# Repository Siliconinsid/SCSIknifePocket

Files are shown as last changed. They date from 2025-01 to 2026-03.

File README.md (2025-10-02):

# SCSIknife Pocket

SCSIknife Pocket - The SCSI jump drive.

SCSIknife Pocket is a ZuluSCSI™ PICO OSHW derivative, compatible with the ZuluSCSI™ PICO firmware.

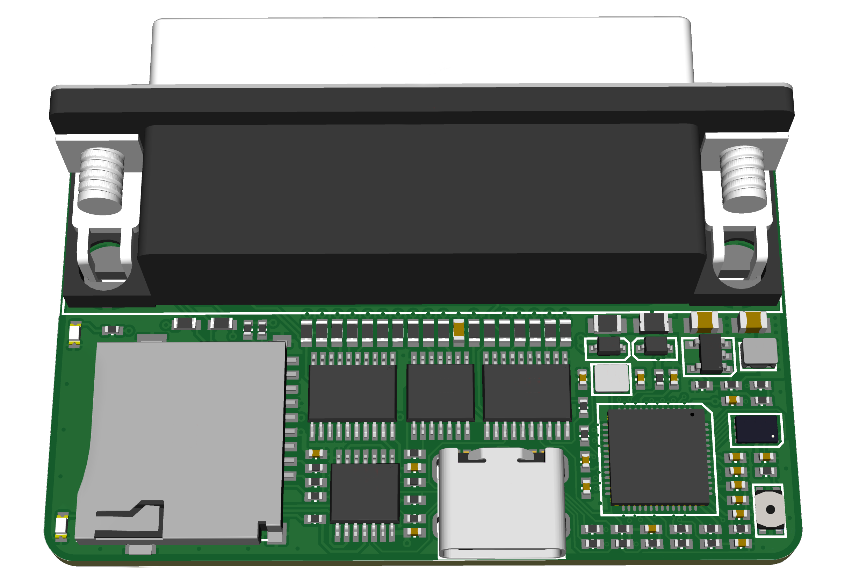
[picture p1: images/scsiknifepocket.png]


SCSIknife Pocket is an extremely compact SCSI disk drive emulator designed to be plugged externally to a computer or SCSI enabled device.

# Hardware

SCSIknife Pocket require 5.0VDC ± 0.5V which can be supplied by the SCSI termination or USB-C. SCSIknife Pocket is available in DB25, HD50 or Centronics50 version.

SCSI DB25 connector is male, but can be replaced with DB25 female if soldered on the underside of the board. The same apply for other connector types.

# Firmware

SCSIknife Pocket is 100% compatible with the ZuluSCSI™ PICO firmware.
As such, flashing instructions can be found [there](https://github.com/ZuluSCSI/ZuluSCSI-firmware)

To update the firmware, download the universal `.zip` archive and place it on a SD card, firmware will be updated at power up.
Alternatively, place the PICO version of the `.bin` file on the SD card. Do not use the RP2040 or any RP2350 based versions.
If for some reason SCSIknife is unresponsive or if the wrong firmware is flashed, restore by pressing and holding the “Bootloader” button before plugging in the USB C connection to a computer. SCSIknife will appear as a drive on the desktop. Drop the PICO firmware file in `.uf2` format on the disk and SCSIknife will automatically update and disconnect itself upon completion. 

# Gerber generation

This PCB was designed with Adobe Illustrator, and exported as SVG files.

These SVG files are then converted to Gerber using the following tools:
* [Gerbolyze](https://github.com/jaseg/gerbolyze)
* [svg-to-gerber](https://github.com/Altomare/svg-to-gerber): gerbolyze wrapper + drill file generation

If you need to re-generate gerbers:
```shell
# Illustrator uses 72 DPI instead of the usual 96 for SVG files
svg-to-gerber.py SCSIknife/svg SCSIknife/gerber 72

# If you end up with a negative gerber on some layers, 
# re-run the svg-flatten command seen in logs without -f.
# It seems to behave differently on different setups
```

# License and disclaimer

SCSIknife Pocket is based on ZuluSCSI™ PICO OSHW, which can be found here:
* [ZuluSCSI™ Pico OSHW](https://github.com/ZuluSCSI/ZuluSCSI-Pico-OSHW)
* [ZuluSCSI™ Firmware](http://github.com/ZuluSCSI/ZuluSCSI-firmware)

ZuluSCSI™ is a registered trademark of Rabbit Hole Computing.
Rabbit Hole Computing is not responsible for the SCSIknife hardware and does not provide technical support and troubleshooting regarding SCSIknife related issues.

SCSIknife Pocket inherits the CERN-OHL-S-2.0 license from ZuluSCSI Pico

See [license.txt](LICENSE.txt)

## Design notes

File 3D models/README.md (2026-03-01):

# Creation of a circuit enclosure

The goal of this project is to create an enclosure for the [SCSI Knife Pocket](https://github.com/Siliconinsid/SCSIknifePocket) circuit.

## A prerequisite to the goal
Such a goal is generally fulfilled thanks to a 3D model of the finished circuit, a side-product of the CAD worflow used to design the circuit, used as a guide to design the enclosure around it.

In this case, the author has provided a PDF image of the layout of the main PCB. A bit of elaboration is needed before to tackle the main goal, the enclosure itself.

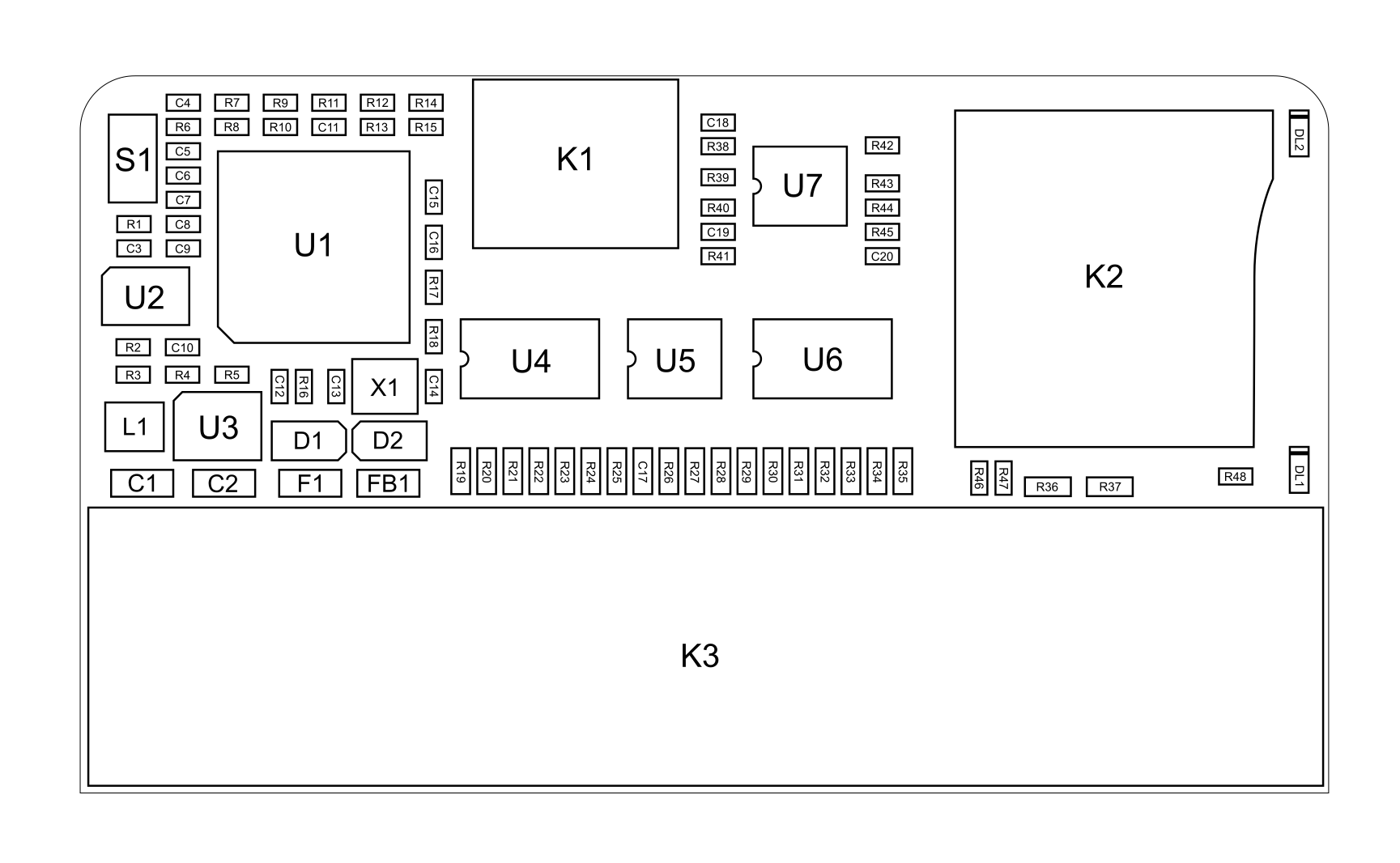
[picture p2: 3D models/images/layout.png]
 

**Note:** In addition to the main goal, attention will be paid to the procedures, they must be simple and reproducible with further versions of the circuit. 

Open Source tools used in this part of the project: 

* **Inkscape** is used to work on the SVG file 
* **FreeCAD** is used for the mechanical design.

An account on the [GrabCAD portal](https://grabcad.com) is also used.

The overall procedure is to start from the layout of the PCB, to simply it, then to import its geometry into the CAD system used for the enclosure design. The geometry of the circuit is transfered from the SVG to the CAD system, then ready-made 3D models of the components are added to recreate a realistic volumetry of the fully equiped circuit.

## Prerequisite elaboration
### Simplify the layout
The input is the file *schematcs/layout.pdf*, it is imported into Inkscape, an Adobe Illustrator® like tool.
Most components of the circuit are low profile CMS components, they require next to nothing in overhead space allocation. Therefore, only the footprint of the largest ones, two connectors and a memory card reader are retained and their precise placement transferred to FreeCAD. Only those four paths remain, the PCB outline and the footprint of the main components.

The result is exported as pcb_simplified.svg

 

### Import into the CAD system
FreeCAD is divided in multiple *Workbenches*, each one is specialized in some specific tasks.

* *Sketcher*: Used to streamline the paths and to reduce all of the remaining "Degrees Of Freedom" or DOF. 
* *Draft*: Used to transform the drawing into CAD sketches.
* *Part*: Used to compose a simplified 3D model of the circuit.

The import happens in the *Draft* workbench, choose *Import...* in the **File** menu, and select *simplified_pcb.svg*, then the second option *"As a geometry"*. Four objets are added to the tree of the model. Select each of them then click on the red/blue icon in the top toolbar to transform each path into a sketch.  Rename them for an easy selection.
Change to the *Sketcher* Workbench. The PCB and the Card Reader have arcs composed with multiple segments causing some green cluttering of the drawing.
    * Replace multiple segments with single arcs primitives. Deactivate all of the constraints, the total number of DOFs is then displayed. 
    * Reduce this number to nothing, with the paths highlighted in a single colour: To do so, add a "blocker" (red X in a circle) constraint on some of the edges. If the addition is not effective in decreasing the number of DOFs, just undo it and try another one. Additional attention is required for the PCB outline which needs to be a closed path. Examine the 6 vertices, if any does not seem a perfect circle, select them and apply a *Coincidence* constraint, reducing all neighbour points to a single one.

### Design and populate the Circuit 3D model

* Give some thickness (about 1.6 mm) to the PCB, by extruding the PCB outline upwards in the *Draft* workbench. This is the only **design** operation performed with this CAD tool.
* Populate the PCB with library 3D models of the 3 components. GrabCAD is a convenient resource for them.    
    * [The DB-25 female angle connector, labeled "AB2_DB25\_F\_RA"](https://grabcad.com/library/db25-female-right-angle-connector-1)
    * [The USB-C female connector, labeled "HRO_TYPE-C-31-M-12"](https://grabcad.com/library/type-c-31-m-12-1)
    * [The TF card reader, labeled "L-KLS1-TF-0.03\_ALL001"](https://grabcad.com/library/tf-01a-1) 

To insert one of those library components, you can download it from the GrabCAD portal through Community/Library menu, after creation of a free account. Ideally, the files are in .STEP format, otherwise on-line tools exist to convert them. The STEP file will be opened as separate document in FreeCAD then the file with the abovementioned labels can be dragged and dropped into the PCB project tree view.

Each objet in FreeCAD can be "placed", then on top of the applied changes from the library view, they can be moved around or rotated again to match the alignment of their footprint in the CAD tool **TOP** view.

Select the component in the tree, in the bottom panel activate the "Data" tab to see and edit the values.

* Placement
    * Angle: ± multiples of 90° to orient the component
    * Axis: Only 1 and 0 values to indicate X, Y or Z 
    * Position: x,y,z distances in millimeters to move the component into its position, use top and front view for precise alignement, it is also recommended to toggle the visibility of the PCB (Eye icon in front of it or selection+spacebar). A vertical z nudge of 1.6 mm (thickness of PCB) is needed to place the component on the top surface of the PCB.
  
Should an additional transform be needed, change to "Part" workbench, select component in the tree and right-click for contextual menu, and select first option, arrows and circular handles allow for additional placement movements.

Finally, select the root of the tree, then select from menu File > Export, choose STEP as the output format, and the circuit 3D model is now saved as pcb_simplified.step

Achievement unlocked! Prerequisite ready! 

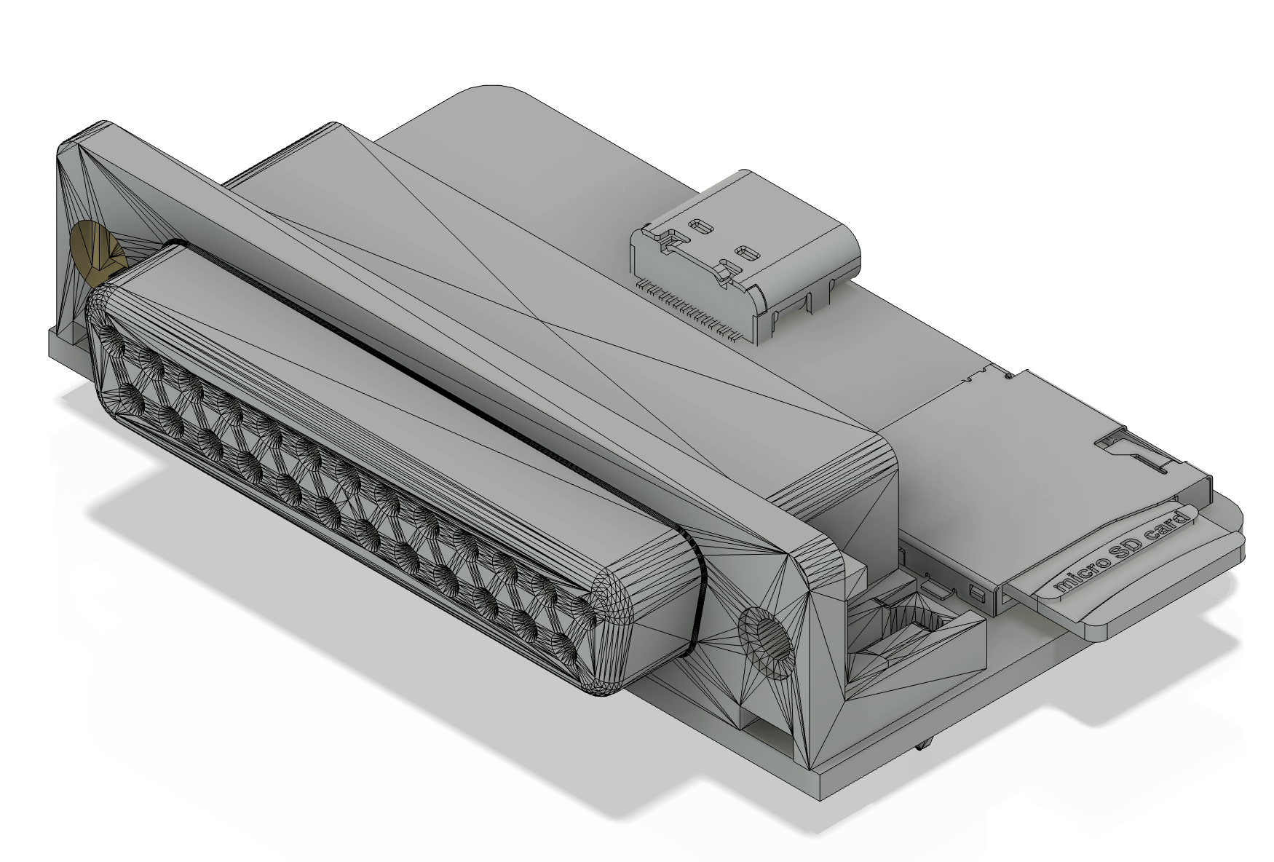
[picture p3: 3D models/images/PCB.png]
 

### Design of the enclosure

The main challenge of the design is to tightly maintain the PCB, with no sliding back and forth, and have the DB-25 "ears" register flush to the back of the computer on which it is mounted. In this version, a thin façade is used.

FreeCAD was first envisaged to finalize the design of this enclosure, however current bugs or lack of documentation on some recent changes have made it impossible to use. The free version of Autodesk Fusion 360 was used instead of that Open Source tool. After many attemps, the design with a sleeve and a back cover was retained. An optional plaque can display a logo, or some custom metal plaque could be stuck on the top surface of the sleeve.  

**Note:** A SCSI disk DB-25 should be of male gender, however only the female model was available as a 3D model. This has no impact on the design itself.

- Front view without sleeve
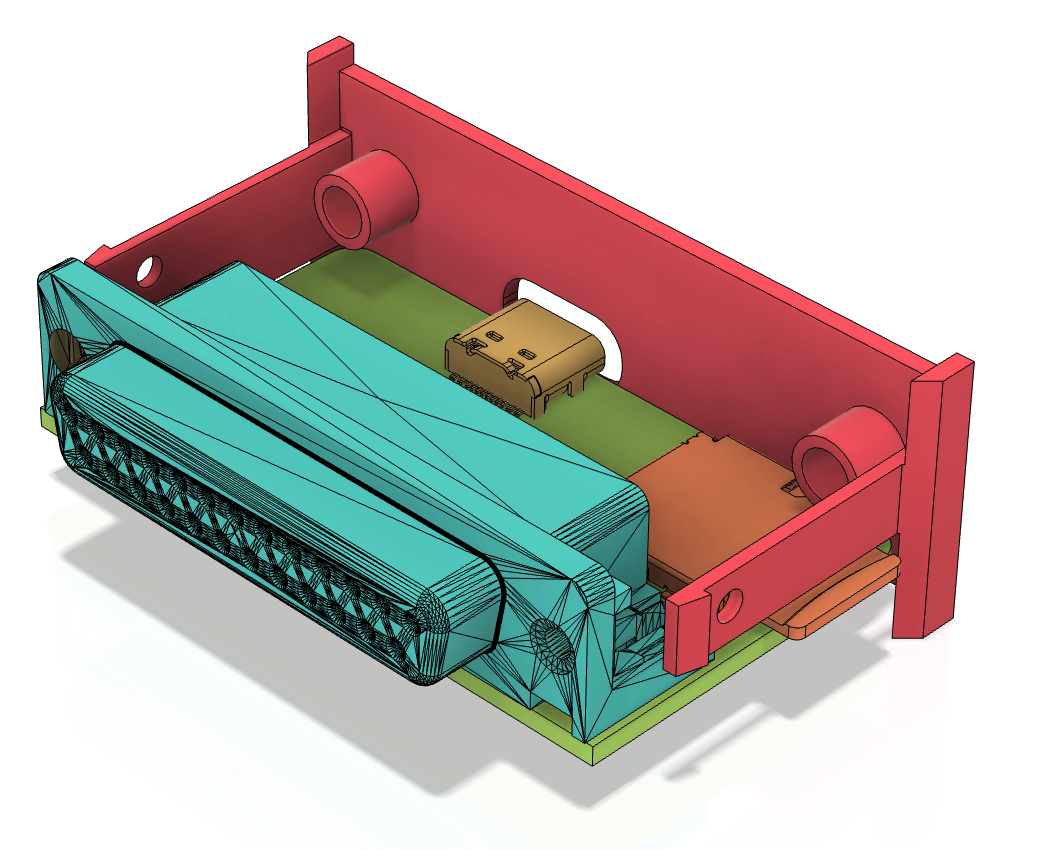
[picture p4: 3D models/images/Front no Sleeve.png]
 

- Front view with sleeve
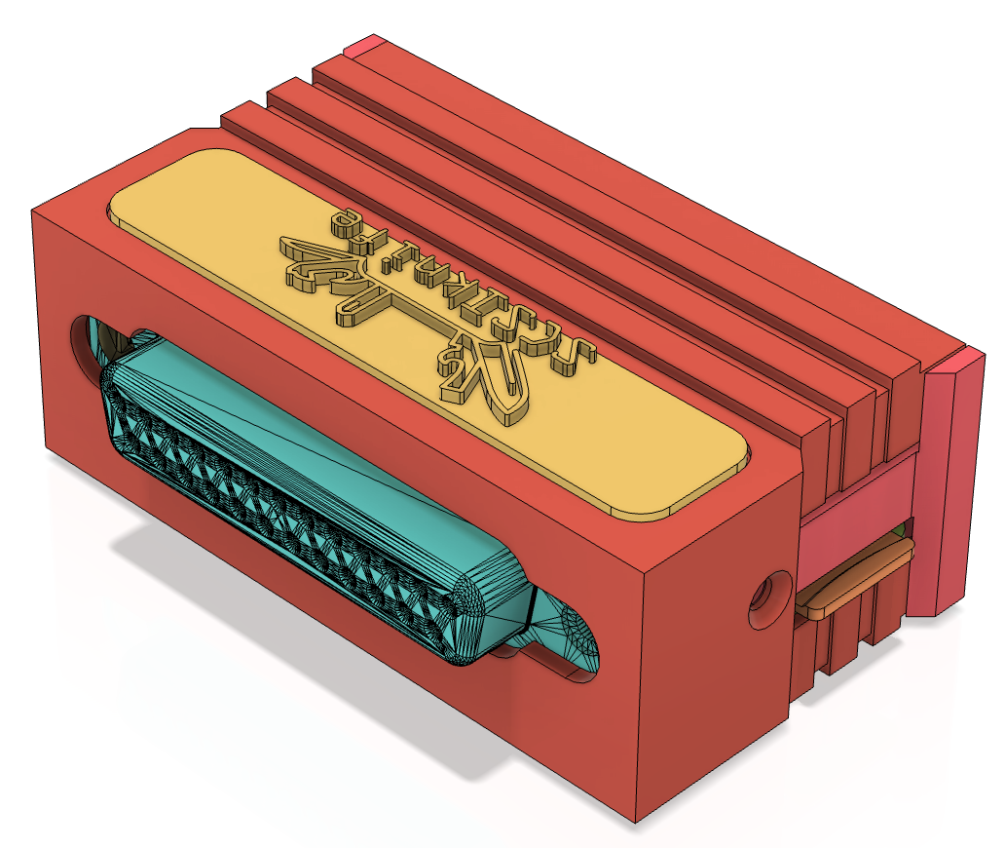
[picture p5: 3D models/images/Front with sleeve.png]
 

- Back view without back cap
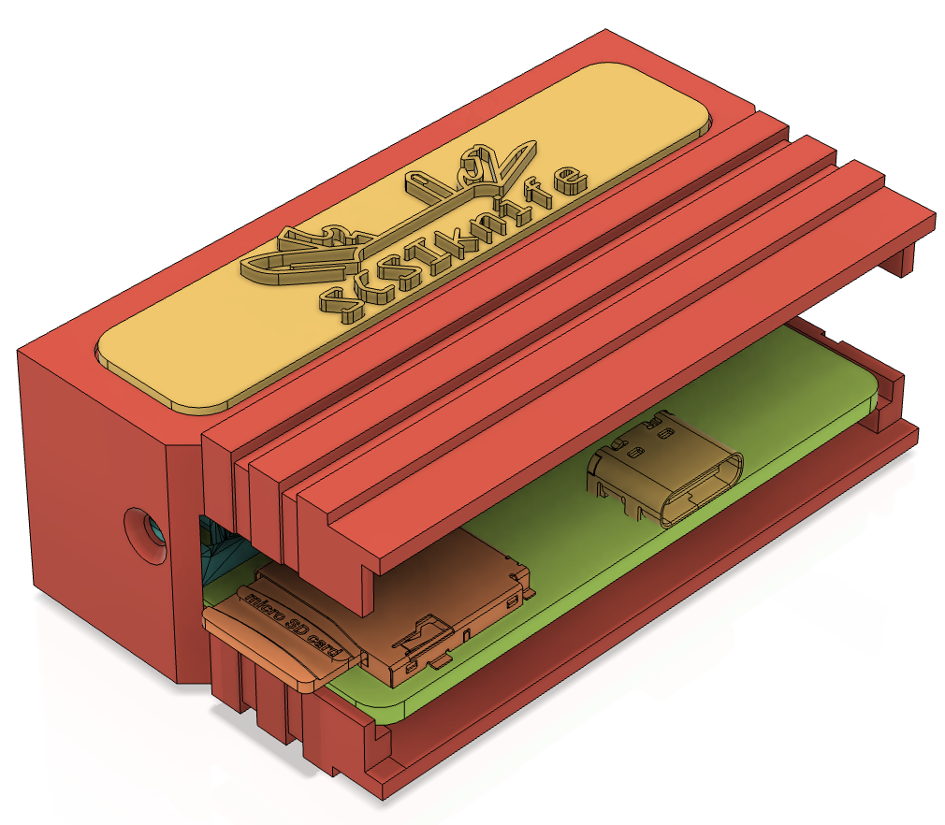
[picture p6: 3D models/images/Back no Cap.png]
 

- Back view with back cap
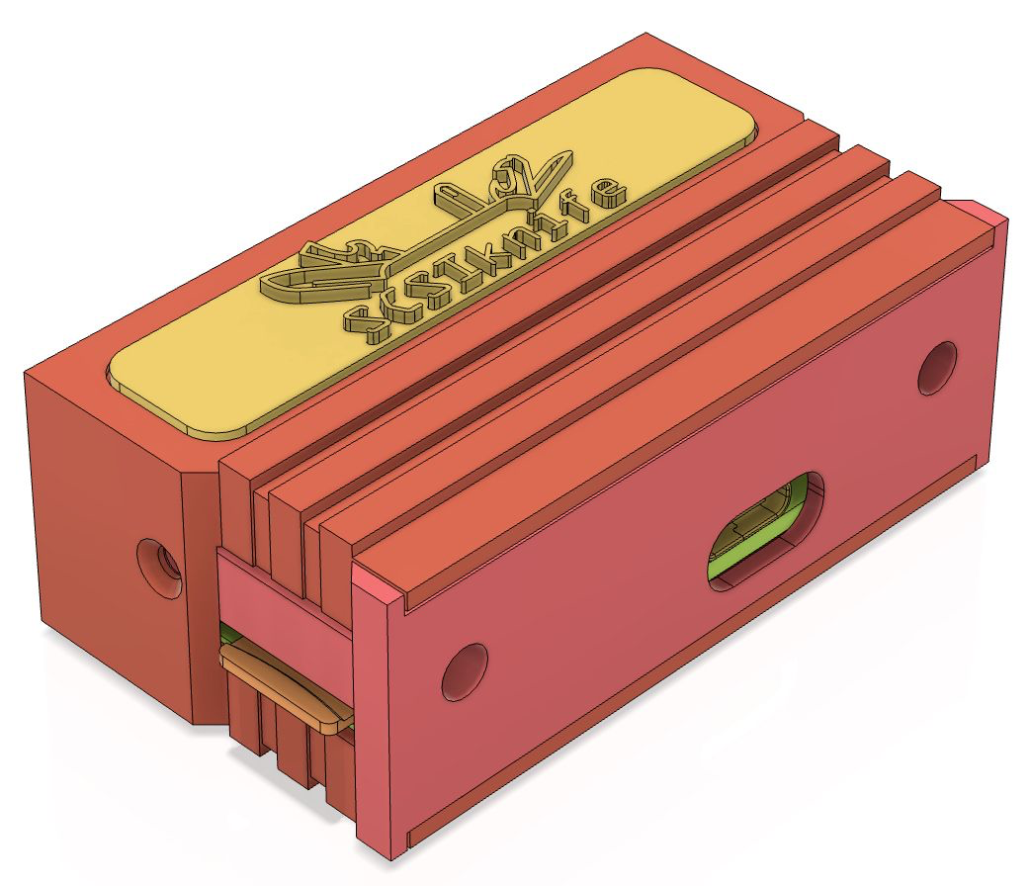
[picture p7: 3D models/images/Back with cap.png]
 

- Long screws could be added to secure the plug to the Mac. [Digikey](https://www.digikey.fr/fr/products/detail/norcomp-inc/160-000-050R031/1008061) has one reference for them.

- And finally...
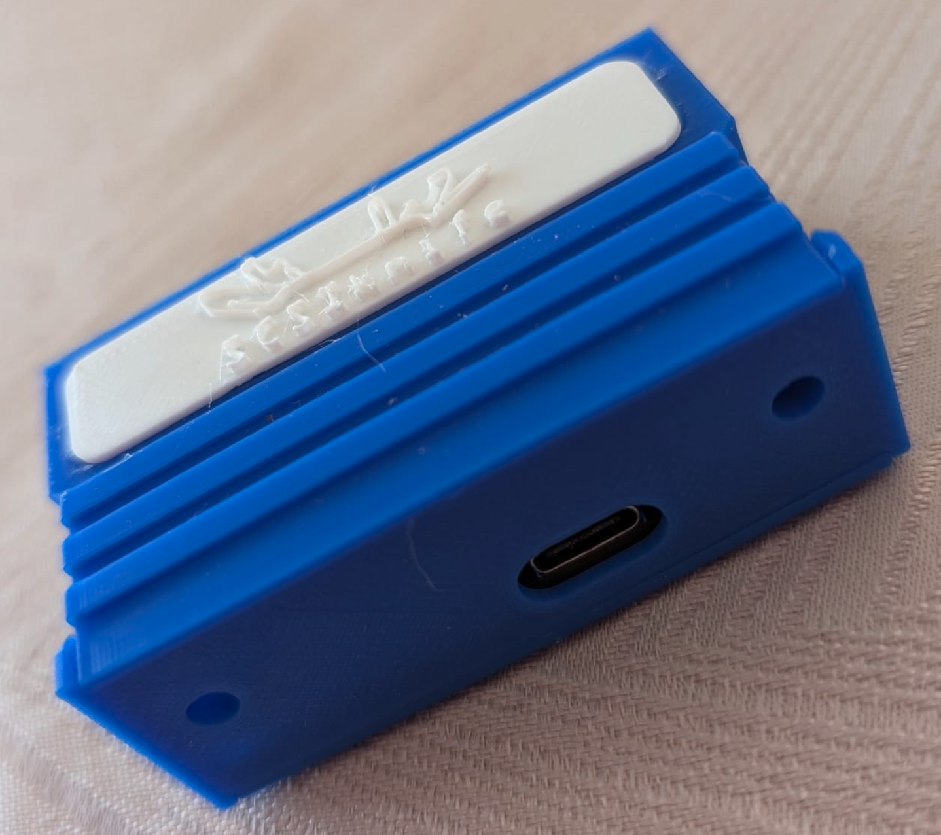
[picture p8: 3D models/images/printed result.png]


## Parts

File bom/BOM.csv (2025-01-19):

Designator | Component | Type | Value | Rating | Voltage | Tolerance | Package | Manufacturer | Part number
R1 | Resistor | Thick film | 1kΩ | 1/16W | 50V | 1% | 0402 | Vishay Dale | CRCW04021K00FKED
R2 | Resistor | Thick film | 5.6kΩ | 1/16W | 50V | 1% | 0402 | Vishay Dale | CRCW04025K60FKED
R3 | Resistor | Thick film | 10kΩ | 1/16W | 50V | 1% | 0402 | Vishay Dale | CRCW040210K0FKED
R4 | Resistor | Thick film | 90.9kΩ | 1/16W | 50V | 1% | 0402 | Vishay Dale | CRCW040290K9FKED
R5 | Resistor | Thick film | 20kΩ | 1/16W | 50V | 1% | 0402 | Vishay Dale | CRCW04022’0K0FKED
R6 | Resistor | Thick film | 200Ω | 1/16W | 50V | 1% | 0402 | Vishay Dale | CRCW0402200RFKED
R7 | Resistor | Thick film | 4.7kΩ | 1/16W | 50V | 1% | 0402 | Vishay Dale | CRCW04024K70FKED
R8 | Resistor | Thick film | 4.7kΩ | 1/16W | 50V | 1% | 0402 | Vishay Dale | CRCW04024K70FKED
R9 | Resistor | Thick film | 4.7kΩ | 1/16W | 50V | 1% | 0402 | Vishay Dale | CRCW04024K70FKED
R10 | Resistor | Thick film | 1kΩ | 1/16W | 50V | 1% | 0402 | Vishay Dale | CRCW04021K00FKED
R11 | Resistor | Thick film | 4.7kΩ | 1/16W | 50V | 1% | 0402 | Vishay Dale | CRCW04024K70FKED
R12 | Resistor | Thick film | 5.1kΩ | 1/16W | 50V | 1% | 0402 | Vishay Dale | CRCW04025K10FKED
R13 | Resistor | Thick film | 5.1kΩ | 1/16W | 50V | 1% | 0402 | Vishay Dale | CRCW04025K10FKED
R14 | Resistor | Thick film | 27Ω | 1/16W | 50V | 1% | 0402 | Vishay Dale | CRCW040227R0FKED
R15 | Resistor | Thick film | 27Ω | 1/16W | 50V | 1% | 0402 | Vishay Dale | CRCW040227R0FKED
R16 | Resistor | Thick film | 4.7kΩ | 1/16W | 50V | 1% | 0402 | Vishay Dale | CRCW04024K70FKED
R17 | Resistor | Thick film | 1kΩ | 1/16W | 50V | 1% | 0402 | Vishay Dale | CRCW04021K00FKED
R18 | Resistor | Thick film | 1kΩ | 1/16W | 50V | 1% | 0402 | Vishay Dale | CRCW04021K00FKED
R19 | Resistor | Thick film | 110Ω | 1/10W | 75V | 1% | 0603 | Vishay Dale | CRCW0603110RFKEA
R20 | Resistor | Thick film | 110Ω | 1/10W | 75V | 1% | 0603 | Vishay Dale | CRCW0603110RFKEA
R21 | Resistor | Thick film | 110Ω | 1/10W | 75V | 1% | 0603 | Vishay Dale | CRCW0603110RFKEA
R22 | Resistor | Thick film | 110Ω | 1/10W | 75V | 1% | 0603 | Vishay Dale | CRCW0603110RFKEA
R23 | Resistor | Thick film | 110Ω | 1/10W | 75V | 1% | 0603 | Vishay Dale | CRCW0603110RFKEA
R24 | Resistor | Thick film | 110Ω | 1/10W | 75V | 1% | 0603 | Vishay Dale | CRCW0603110RFKEA
R25 | Resistor | Thick film | 110Ω | 1/10W | 75V | 1% | 0603 | Vishay Dale | CRCW0603110RFKEA
R26 | Resistor | Thick film | 110Ω | 1/10W | 75V | 1% | 0603 | Vishay Dale | CRCW0603110RFKEA
R27 | Resistor | Thick film | 110Ω | 1/10W | 75V | 1% | 0603 | Vishay Dale | CRCW0603110RFKEA
R28 | Resistor | Thick film | 110Ω | 1/10W | 75V | 1% | 0603 | Vishay Dale | CRCW0603110RFKEA
R29 | Resistor | Thick film | 110Ω | 1/10W | 75V | 1% | 0603 | Vishay Dale | CRCW0603110RFKEA
R30 | Resistor | Thick film | 110Ω | 1/10W | 75V | 1% | 0603 | Vishay Dale | CRCW0603110RFKEA
R31 | Resistor | Thick film | 110Ω | 1/10W | 75V | 1% | 0603 | Vishay Dale | CRCW0603110RFKEA
R32 | Resistor | Thick film | 110Ω | 1/10W | 75V | 1% | 0603 | Vishay Dale | CRCW0603110RFKEA
R33 | Resistor | Thick film | 110Ω | 1/10W | 75V | 1% | 0603 | Vishay Dale | CRCW0603110RFKEA
R34 | Resistor | Thick film | 110Ω | 1/10W | 75V | 1% | 0603 | Vishay Dale | CRCW0603110RFKEA
R35 | Resistor | Thick film | 110Ω | 1/10W | 75V | 1% | 0603 | Vishay Dale | CRCW0603110RFKEA
R36 | Resistor | Thick film | 110Ω | 1/10W | 75V | 1% | 0603 | Vishay Dale | CRCW0603110RFKEA
R37 | Resistor | Thick film | 110Ω | 1/10W | 75V | 1% | 0603 | Vishay Dale | CRCW0603110RFKEA
R38 | Resistor | Thick film | 4.7kΩ | 1/16W | 50V | 1% | 0402 | Vishay Dale | CRCW04024K70FKED
R39 | Resistor | Thick film | 4.7kΩ | 1/16W | 50V | 1% | 0402 | Vishay Dale | CRCW04024K70FKED
R40 | Resistor | Thick film | 1kΩ | 1/16W | 50V | 1% | 0402 | Vishay Dale | CRCW04021K00FKED
R41 | Resistor | Thick film | 1kΩ | 1/16W | 50V | 1% | 0402 | Vishay Dale | CRCW04021K00FKED
R42 | Resistor | Thick film | 120Ω | 1/16W | 50V | 1% | 0402 | Vishay Dale | CRCW0402120RFKED
R43 | Resistor | Thick film | 4.7kΩ | 1/16W | 50V | 1% | 0402 | Vishay Dale | CRCW04024K70FKED
R44 | Resistor | Thick film | 4.7kΩ | 1/16W | 50V | 1% | 0402 | Vishay Dale | CRCW04024K70FKED
R45 | Resistor | Thick film | 4.7kΩ | 1/16W | 50V | 1% | 0402 | Vishay Dale | CRCW04024K70FKED
R46 | Resistor | Thick film | 4.7kΩ | 1/16W | 50V | 1% | 0402 | Vishay Dale | CRCW04024K70FKED
R47 | Resistor | Thick film | 4.7kΩ | 1/16W | 50V | 1% | 0402 | Vishay Dale | CRCW04024K70FKED
R48 | Resistor | Thick film | 51Ω | 1/16W | 50V | 1% | 0402 | Vishay Dale | CRCW040251R0FKED
C1 | Capacitor | MLCC | 10µF | X7R | 25V | 10% | 0805 | Murata | GRM21BZ71E106KE15L
C2 | Capacitor | MLCC | 22µF | X5R | 16V | 20% | 0805 | Samsung | CL10A226MO7JZNC
C3 | Capacitor | MLCC | 2.2uF | X5R | 25V | 20% | 0402 | Murata Electronics | GRM155R61E225ME11D
C4 | Capacitor | MLCC | 100nF | X7R | 50V | 20% | 0402 | Murata Electronics | GRM155R71H104ME14J
C5 | Capacitor | MLCC | 2.2uF | X5R | 25V | 20% | 0402 | Murata Electronics | GRM155R61E225ME11D
C6 | Capacitor | MLCC | 2.2uF | X5R | 25V | 20% | 0402 | Murata Electronics | GRM155R61E225ME11D
C7 | Capacitor | MLCC | 2.2uF | X5R | 25V | 20% | 0402 | Murata Electronics | GRM155R61E225ME11D
C8 | Capacitor | MLCC | 100nF | X7R | 50V | 20% | 0402 | Murata Electronics | GRM155R71H104ME14J
C9 | Capacitor | MLCC | 100nF | X7R | 50V | 20% | 0402 | Murata Electronics | GRM155R71H104ME14J
C10 | Capacitor | MLCC | 100nF | X7R | 50V | 20% | 0402 | Murata Electronics | GRM155R71H104ME14J
C11 | Capacitor | MLCC | 100nF | X7R | 50V | 20% | 0402 | Murata Electronics | GRM155R71H104ME14J
C12 | Capacitor | MLCC | 100nF | X7R | 50V | 20% | 0402 | Murata Electronics | GRM155R71H104ME14J
C13 | Capacitor | MLCC | 15pF | C0G | 50V | 1% | 0402 | Murata Electronics | GRM1555C1H150FA01D
C14 | Capacitor | MLCC | 15pF | C0G | 50V | 1% | 0402 | Murata Electronics | GRM1555C1H150FA01D
C15 | Capacitor | MLCC | 100nF | X7R | 50V | 20% | 0402 | Murata Electronics | GRM155R71H104ME14J
C16 | Capacitor | MLCC | 100nF | X7R | 50V | 20% | 0402 | Murata Electronics | GRM155R71H104ME14J
C17 | Capacitor | MLCC | 12pF | C0G | 25V | 2% | 0603 | Vishay Vitramon | VJ0603A120GXXCW1BC
C18 | Capacitor | MLCC | 100nF | X7R | 50V | 20% | 0402 | Murata Electronics | GRM155R71H104ME14J
C19 | Capacitor | MLCC | 100nF | X7R | 50V | 20% | 0402 | Murata Electronics | GRM155R71H104ME14J
C20 | Capacitor | MLCC | 2.2uF | X5R | 25V | 20% | 0402 | Murata Electronics | GRM155R61E225ME11D
F1 | PTC | Polymer | 750mA | 50A | 12V |  | 0805 | Bourns | MF-PSML075/12-2
FB1 | Ferrite |  | 300mΩ | 500mA |  |  | 0805 | Laird | HZ0805E601R-10
L1 | Inductor |  | 2.2µH | 1.25A |  |  |  | Würth Elektronik | 74405020022
X1 | Crystal |  | 12MHz |  |  |  |  | Abracon | ABM10AIG-12.000MHZ-4Z-T3
D1 | Diode | Schottky | B5819W | 1A | 40V |  | SOD323 | Micro Commercial Components | B5819WS-TP
D2 | Diode | Schottky | B5819W | 1A | 40V |  | SOD323 | Micro Commercial Components | B5819WS-TP
DL1 | Diode | LED | Yellow-green | 20mA | 2V |  | 0603 | Würth Elektronik | 150060VS75000
DL2 | Diode | LED | Yellow | 20mA | 2V |  | 0603 | Würth Elektronik | 150060YS75000
U1 | Integrated circuit | Microcontroller | RP2040 |  |  |  | QFN56 | Raspberry Pi | SC0914(13)
U2 | Integrated circuit | Flash memory | W25Q16JV |  |  |  | USON8 | Winbond | W25Q16JVUXIM TR
U3 | Integrated circuit | Switching regulator | RT5796A | 1.5A | Adjustable |  | SOT23-5 | Richtek | RT5796AHGJ5
U4 | Integrated circuit | Bus transceiver | SN74LVT245 |  |  |  | TSSOP20 | Texas Instruments | SN74LVT245BPWR
U5 | Integrated circuit | Buffer | SN74LVT125 |  |  |  | TSSOP14 | Texas Instruments | SN74LVT125PWR
U6 | Integrated circuit | Bus transceiver | SN74LVT245 |  |  |  | TSSOP20 | Texas Instruments | SN74LVT245BPWR
U7 | Integrated circuit | Buffer | SN74LVT125 |  |  |  | TSSOP14 | Texas Instruments | SN74LVT125PWR
S1 | Switch | Tactile switch |  |  |  |  |  | Panasonic | EVP-BL2A1B000
K1 | Connector | USB-C |  |  |  |  |  | Amphenol | 12402012E212A
K2 | Connector | Micro SD card |  |  |  |  |  | CUI Devices | MSD-1-A
K3 | Connector | DB-25 |  | Male |  |  |  | Adam Tech | DB25-PL-24

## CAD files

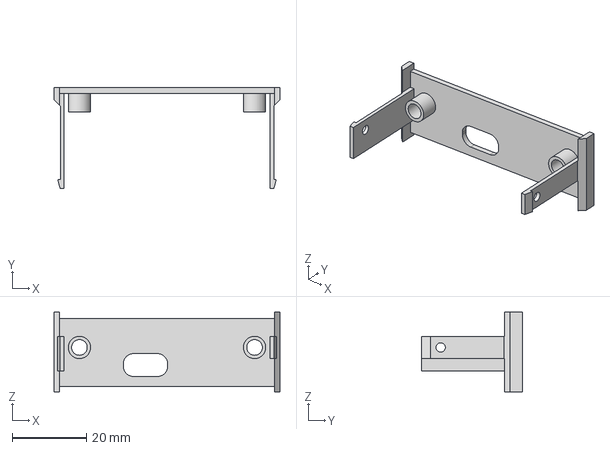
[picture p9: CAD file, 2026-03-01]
3D models/Back.step
60.7 x 27.0 x 21.4 mm

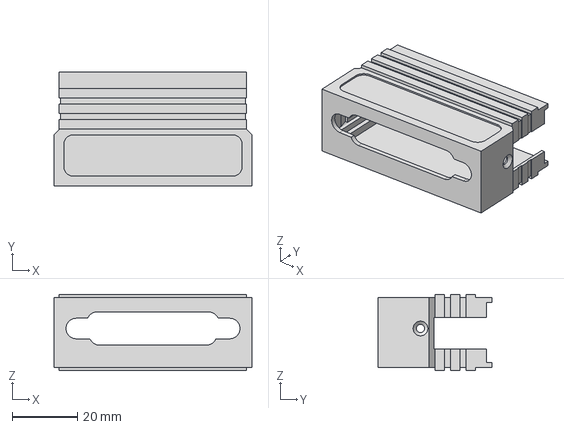
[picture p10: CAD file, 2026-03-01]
3D models/Sleeve.step
60.7 x 34.9 x 23.4 mm

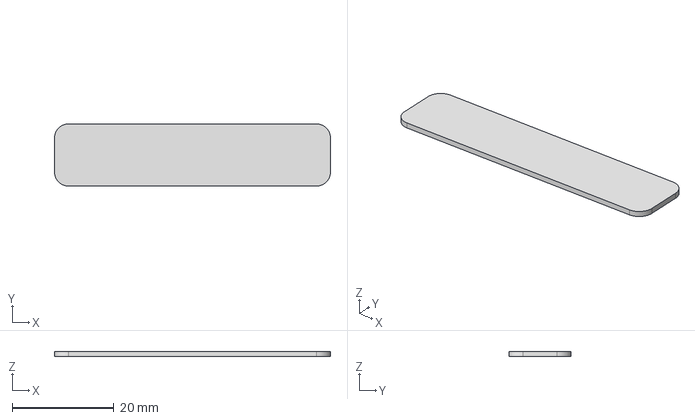
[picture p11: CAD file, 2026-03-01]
3D models/Plaque.step
54.2 x 12.2 x 1.00 mm

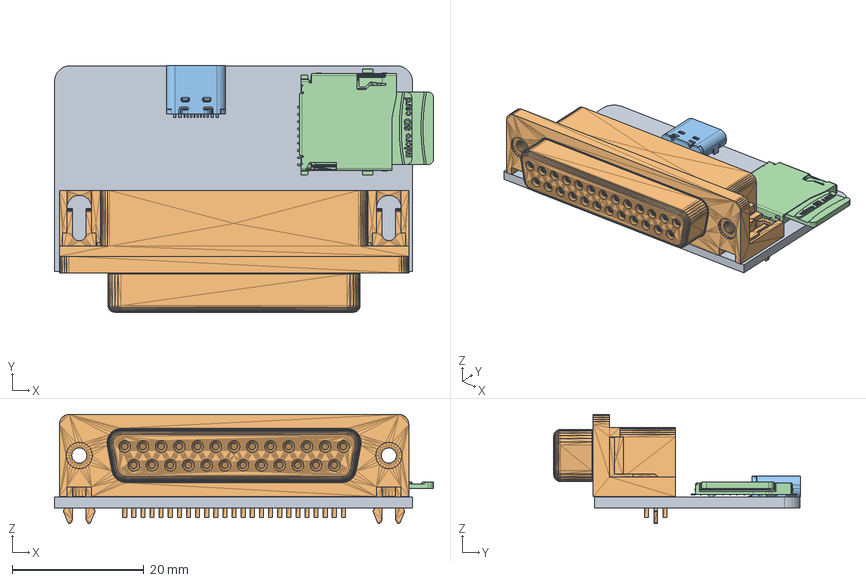
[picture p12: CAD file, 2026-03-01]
3D models/pcb_simplified.FCStd
57.6 x 37.5 x 16.6 mm
PCB001
AB2_DB25_F_RA
HRO_TYPE-C-31-M-12
L-KLS1-TF-003_ALL001

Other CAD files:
3D models/Back.stl
3D models/Plaque.stl
3D models/Sleeve.stl

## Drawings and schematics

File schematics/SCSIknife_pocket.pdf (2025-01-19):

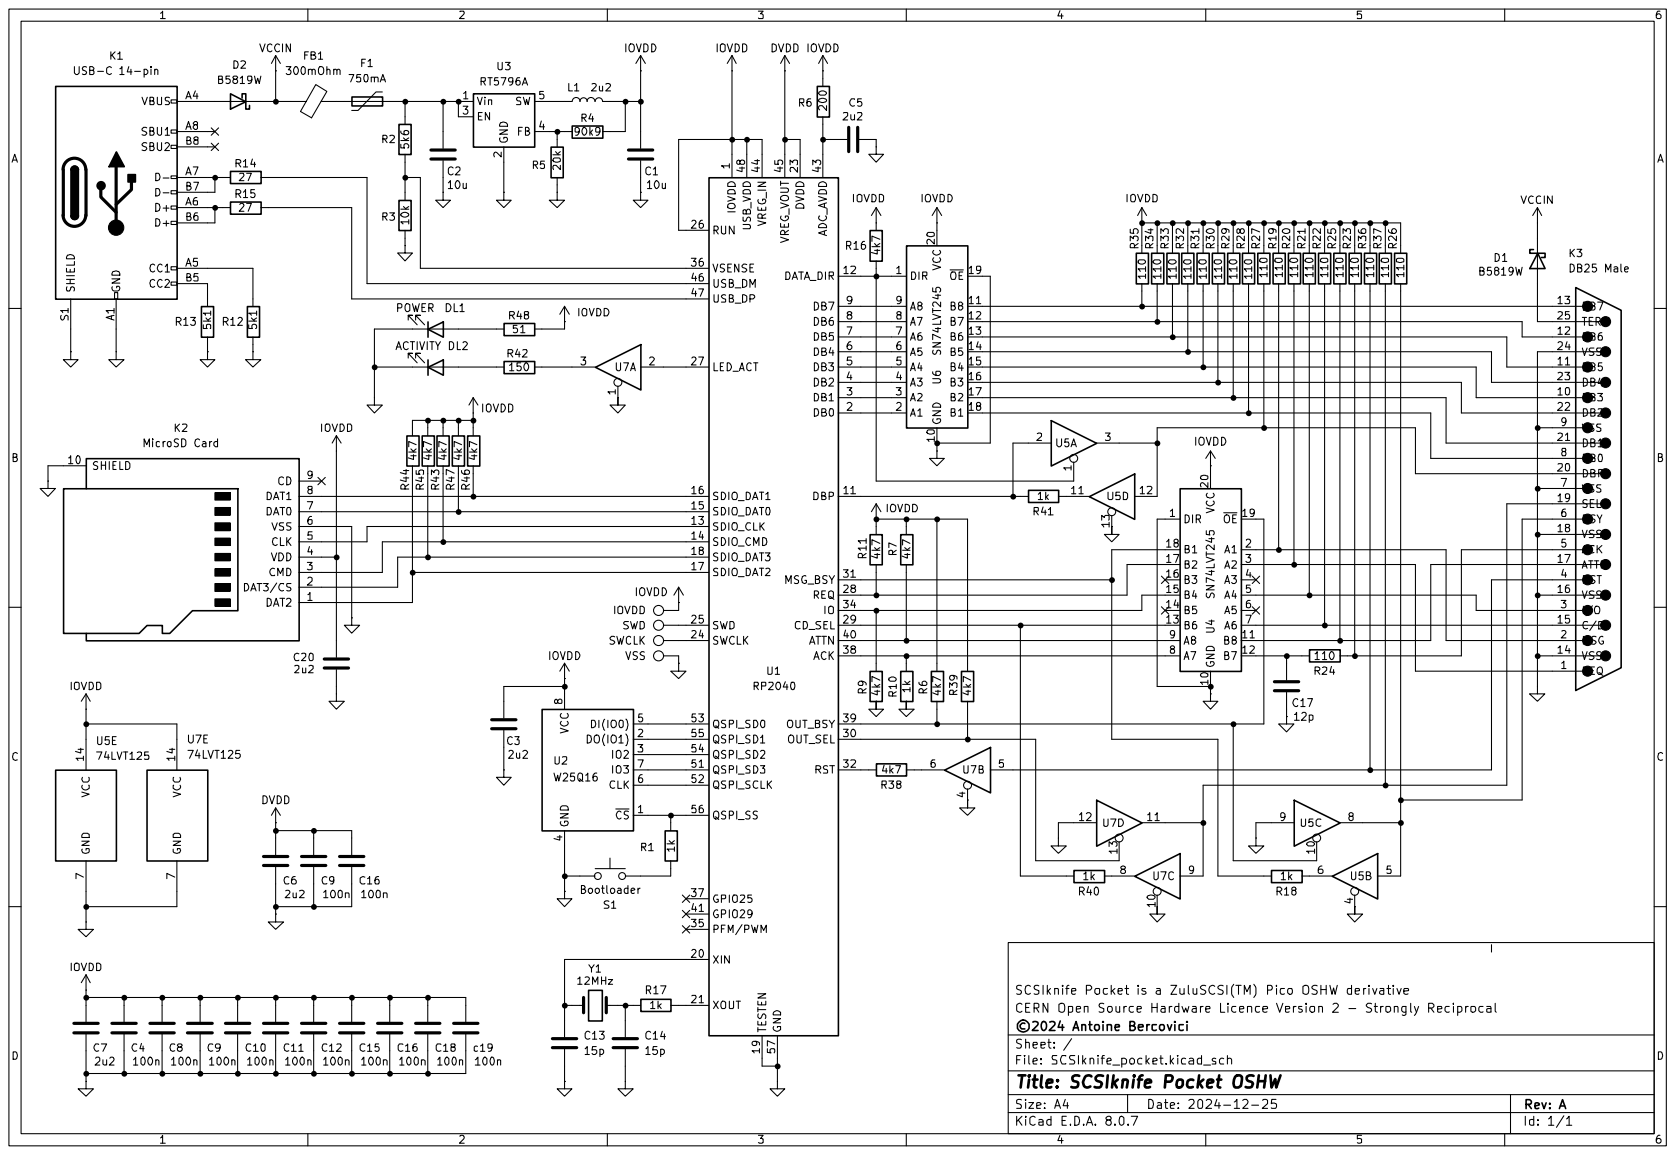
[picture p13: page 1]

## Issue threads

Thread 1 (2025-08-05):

CPL files are missing

Deftaudio, 2025-08-05:
Hi, thank you for redesigning ZuluSCSI Pico in a better form factor. I wanted to order several assembled PCBs and can't see CPL file in the. Would you be able to provide it? Also it might be better to host an orderable project at PCBway, so others can place the order easily and you could get some credit as well.
Thank you!

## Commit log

2025-09-15 Update to connector types
    [KnifePocketCentroGit.drl, KnifePocketCentroGit.gbl, KnifePocketCentroGit.gbo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]
2026-02-28 De-personalize Plaque component (Legal issue avoidance)
    [Plaque.step, Plaque.stl]
2026-02-28 Change printed result picture (no plaque)
2026-02-28 New Logo
    [Plaque.step, Plaque.stl]
